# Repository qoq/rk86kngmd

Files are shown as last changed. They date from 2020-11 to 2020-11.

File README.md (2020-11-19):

# rk86kngmd

A replica of 1993 floppy disc controller for "Radio-86RK" computers. Built around i8255 PPI chip (Soviet clone: КР580ВВ55А) and a handful of discrete logic chips.

This version is a compact rework of the replica. 

- Compact layout
- 74LS series SOIC chips are used instead of DIP 555 logic
- Kept КР580ВВ55А and К155ИР13 as they are much easier to source than i8255 and 74LS198
- 28-pin ROM socket accepts 27C32 or 27C64 EPROM chips
- Added 34-pin standard floppy cable connector and 4-pin Berg power supply connector (+5v/+12v)
- Added AND circutry (2 diodes) to form ROM CS signal from CS1/CS2
- Added two bypass capacitors for stability

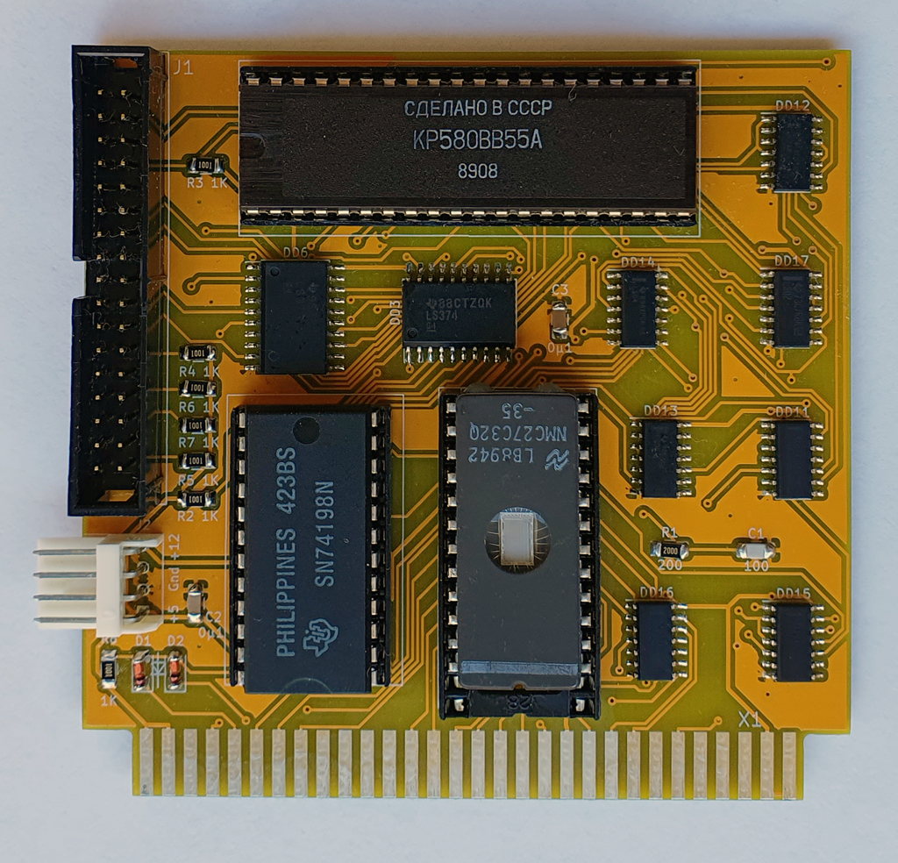
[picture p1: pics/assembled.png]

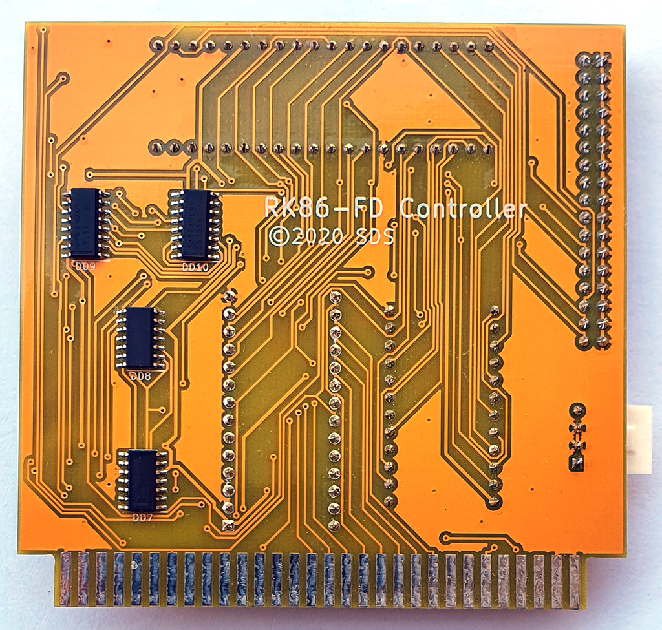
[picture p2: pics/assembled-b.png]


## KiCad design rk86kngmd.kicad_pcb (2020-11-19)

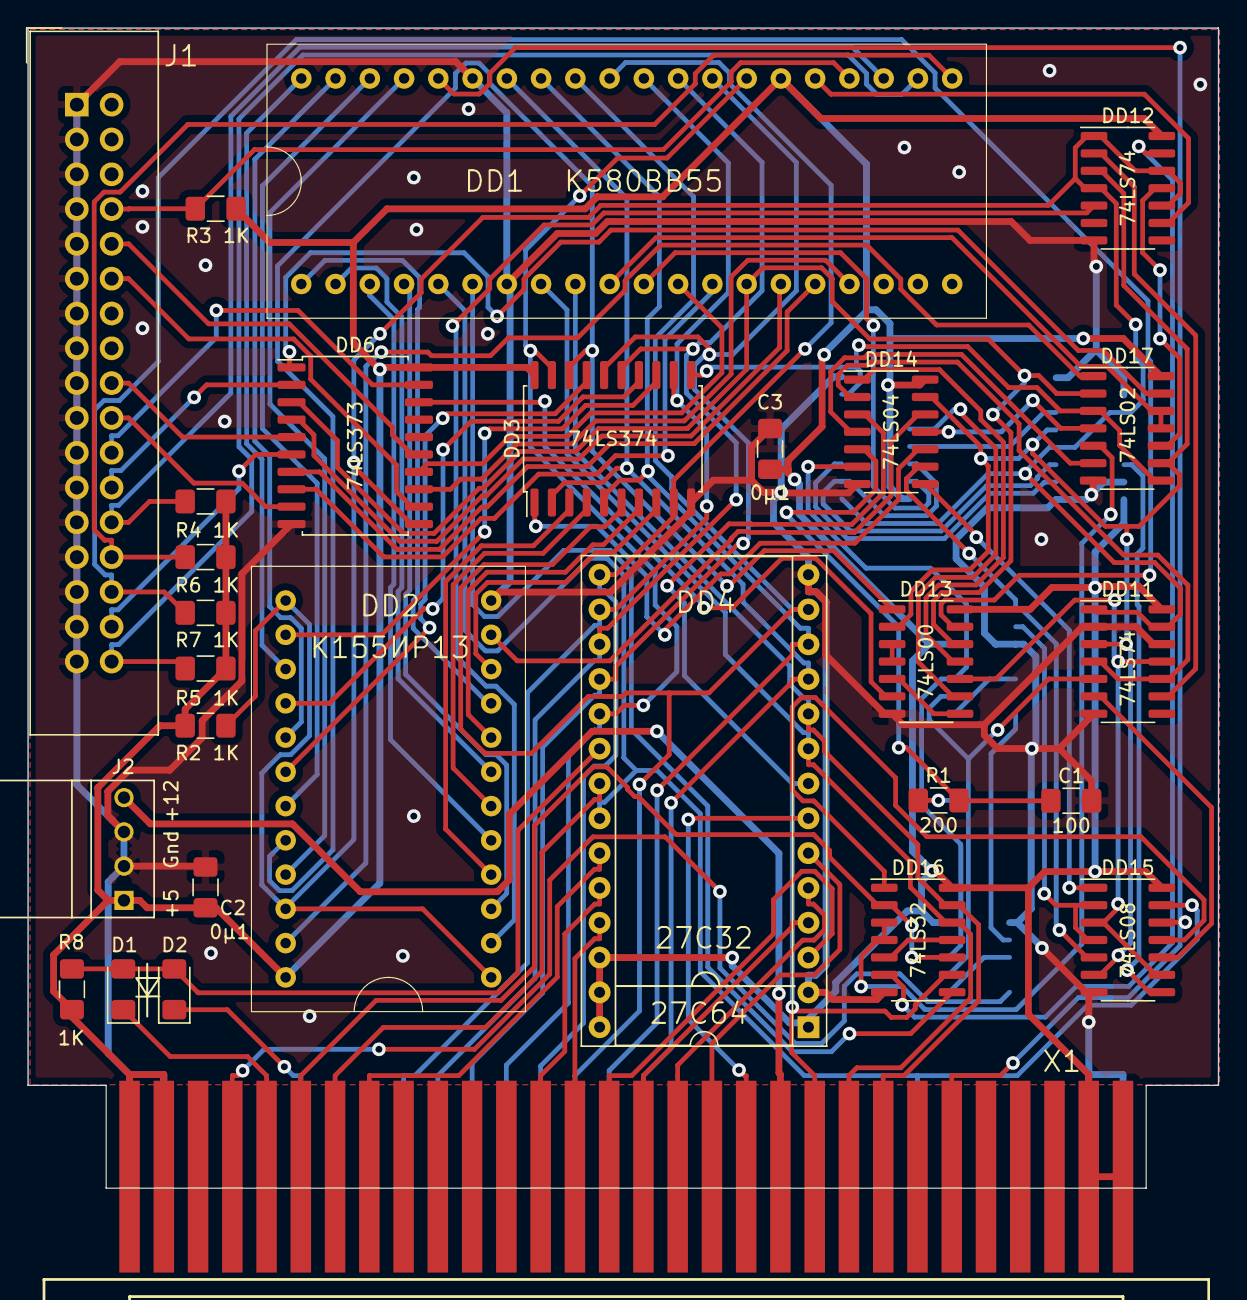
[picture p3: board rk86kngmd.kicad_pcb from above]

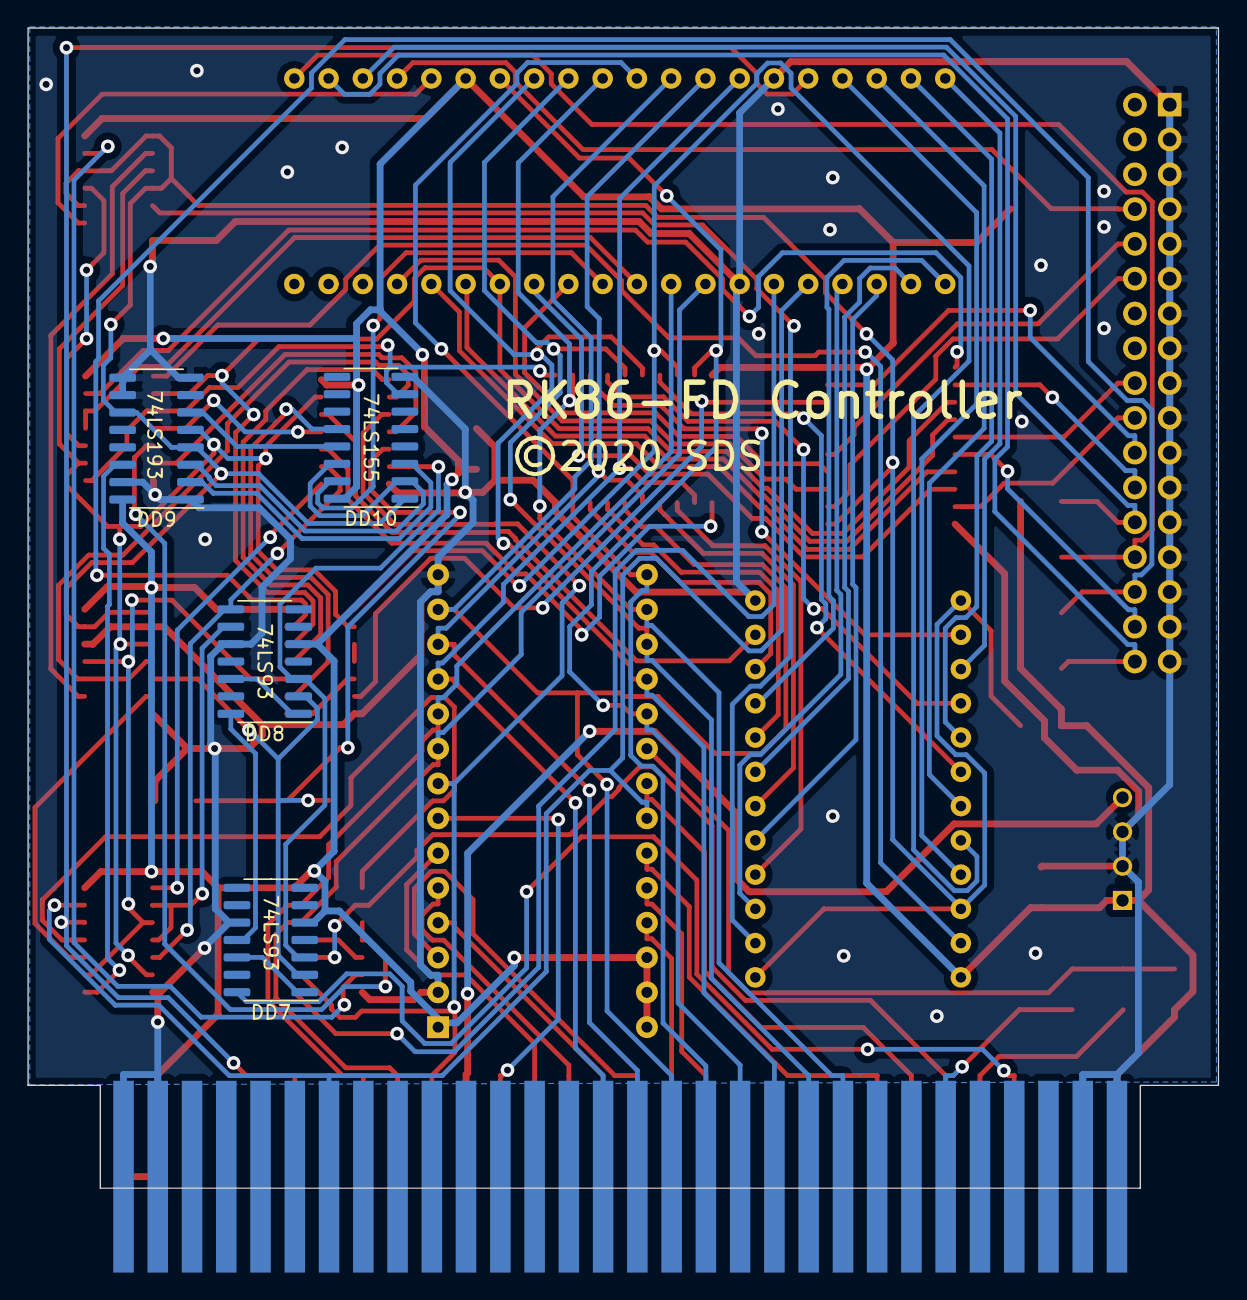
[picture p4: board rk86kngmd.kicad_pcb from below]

Board: 2 copper layers, 86.9 x 84.7 mm, 32 parts (4 on the bottom side), 105 nets.

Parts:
C1: 100; C_1206_3216Metric_Pad1.42x1.75mm_HandSolder
C2, C3: 0μ1; C_1206_3216Metric_Pad1.42x1.75mm_HandSolder
D1, D2: 2N4148; D_1206_3216Metric_Pad1.42x1.75mm_HandSolder
DD1: К580ВВ55; DIP40-2.5mm
DD2: К155ИР13; DIP24-2.5mm
DD3: 74LS374; SOIC-20W_7.5x12.8mm_P1.27mm
DD4: 27C64; DIP-28_W15.24mm_Socket
DD6: 74LS373; SOIC-20W_7.5x12.8mm_P1.27mm
DD7, DD8: 74LS93; SOIC-14_3.9x8.7mm_P1.27mm
DD9: 74LS193; SOIC-16_3.9x9.9mm_P1.27mm
DD10: 74LS155; SOIC-16_3.9x9.9mm_P1.27mm
DD11, DD12: 74LS74; SOIC-14_3.9x8.7mm_P1.27mm
DD13: 74LS00; SOIC-14_3.9x8.7mm_P1.27mm
DD14: 74LS04; SOIC-14_3.9x8.7mm_P1.27mm
DD15: 74LS08; SOIC-14_3.9x8.7mm_P1.27mm
DD16: 74LS32; SOIC-14_3.9x8.7mm_P1.27mm
DD17: 74LS02; SOIC-14_3.9x8.7mm_P1.27mm
J1: Conn_02x17_Odd_Even; IDC-Header_2x17_P2.54mm_Vertical
J2: FD power; TE_171826-4
R1: 200; R_1206_3216Metric_Pad1.42x1.75mm_HandSolder
R2, R3, R4, R5, R6, R7, R8: 1K; R_1206_3216Metric_Pad1.42x1.75mm_HandSolder
X1: ОНп-КС-23

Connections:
+5V: C2.1, C3.1, DD1.26, DD2.24, DD3.20, DD4.1, DD4.26, DD4.27, DD4.28, DD6.20, DD7.5, DD8.5, DD9.16, DD10.16, DD11.14, DD12.14, DD13.14, DD14.14, DD15.14, DD16.14, DD17.14, J2.1, R2.2, R3.1, R4.1, R5.1, R6.1, R7.1, R8.2, X1.B1, X1.B2, X1.B29, X1.B30
+12V: J2.4, X1.B11
/17: DD2.11, DD14.12
/18: DD3.1, DD14.10
/A0: DD1.9, DD4.10, DD16.13, X1.B8
/A1: DD1.8, DD4.9, DD16.12, X1.B9
/A2: DD4.8, DD14.3, DD16.9, X1.B10
/A3: DD4.7, X1.B12
/A4: DD4.6, X1.B13
/A5: DD4.5, X1.B14
/A6: DD4.4, X1.B15
/A7: DD4.3, X1.B16
/A8: DD4.25, X1.B17
/A9: DD4.24, X1.B18
/A10: DD4.21, X1.B24
/A11: DD4.23, X1.B23
/CS1: D1.1, X1.B26
/CS2: D2.1, X1.A25
/CS3: DD16.2, DD16.10, X1.B25
/CS12: D1.2, D2.2, DD4.20, R8.1
/D0: DD1.34, DD3.2, DD4.11, X1.A15
/D1: DD1.33, DD3.5, DD4.12, X1.A16
/D2: DD1.32, DD3.6, DD4.13, X1.A17
/D3: DD1.31, DD3.9, DD4.15, X1.A18
/D4: DD1.30, DD3.12, DD4.16, X1.A22
/D5: DD1.29, DD3.15, DD4.17, X1.A21
/D6: DD1.28, DD3.16, DD4.18, X1.A20
/D7: DD1.27, DD3.19, DD4.19, X1.A19
/OSC: DD7.14, X1.B27
/PB7: DD1.25, DD12.9
/PC1: DD1.15, DD6.4
/PC2: DD1.16, DD6.7
/PC3: DD1.17, DD6.13
/PC4: DD1.13, DD6.8
/PC5: DD1.12, DD6.14
/PC6: DD1.11, DD10.15
/PC7: DD1.10, DD17.11, DD17.12
/RD: DD1.5, DD4.22, DD15.13, X1.A7
/WR: DD1.36, DD15.12, X1.B6
/WRDATA: DD6.18, DD13.6
/WRGATE: DD1.14, DD6.3, DD13.12, DD17.2
DIR: DD6.5, J1.18
DISC_A: DD6.15, J1.10
DISC_B: DD6.12, J1.12
GND: C1.2, C2.2, C3.2, DD1.7, DD1.35, DD2.12, DD3.10, DD4.2, DD4.14, DD6.10, DD7.10, DD8.10, DD9.1, DD9.8, DD9.9, DD9.10, DD9.15, DD10.8, DD11.2, DD11.7, DD11.12, DD12.7, DD13.7, DD14.7, DD15.7, DD16.7, DD17.7, J1.1, J1.3, J1.5, J1.7, J1.9, J1.11, J1.13, J1.15, J1.17, J1.19, J1.21, J1.23, J1.25, J1.27, J1.29, J1.31, J1.33, J2.2, J2.3, X1.A1, X1.A2, X1.A29, X1.A30
IP: DD1.24, J1.8, R3.2
unnamed: C1.1, DD14.5, R1.2
unnamed: DD1.1, DD2.9
unnamed: DD1.2, DD2.7
unnamed: DD1.3, DD2.5
unnamed: DD1.4, DD2.3
unnamed: DD1.6, DD16.8
unnamed: DD1.37, DD2.21
unnamed: DD1.38, DD2.19
unnamed: DD1.39, DD2.17
unnamed: DD1.40, DD2.15
unnamed: DD2.4, DD3.3
unnamed: DD2.6, DD3.4
unnamed: DD2.8, DD3.7
unnamed: DD2.10, DD3.8
unnamed: DD2.14, DD3.13
unnamed: DD2.16, DD3.14
unnamed: DD2.18, DD3.17
unnamed: DD7.1, DD7.12
unnamed: DD7.11, DD8.14
unnamed: DD8.1, DD8.12
unnamed: DD2.1, DD2.13, DD2.22, DD6.11, DD9.4, DD9.11, DD10.1, DD11.1, DD11.13, DD12.1, DD12.4, DD12.10, DD12.12, R2.1
unnamed: DD9.2, DD10.3
unnamed: DD3.11, DD10.7, DD17.3, DD17.8
unnamed: DD10.12, DD13.9
unnamed: DD9.6, DD10.13
unnamed: DD9.3, DD10.2, DD10.14
unnamed: DD9.5, DD11.3, DD12.3, DD13.2, DD14.13, DD15.6, DD17.9
unnamed: DD7.2, DD8.2, DD11.5, R1.1
unnamed: DD11.6, DD15.10
unnamed: DD11.9, DD12.2
unnamed: DD11.4, DD11.10, DD14.2
unnamed: DD11.11, DD13.10, DD15.3, DD15.9
unnamed: DD2.2, DD12.5
unnamed: DD12.11, DD17.10
unnamed: DD12.13, DD16.6
unnamed: DD2.20, DD3.18, DD13.1
unnamed: DD13.3, DD13.4
unnamed: DD13.5, DD13.8
unnamed: DD13.11, DD14.1
unnamed: DD14.4, DD17.6
unnamed: DD7.3, DD8.3, DD14.6
unnamed: DD14.8, DD15.1
unnamed: DD8.8, DD14.9, DD15.5
unnamed: DD14.11, DD17.4
unnamed: DD8.9, DD15.2, DD15.4
unnamed: DD9.14, DD15.8
unnamed: DD15.11, DD16.1
unnamed: DD16.3, DD16.4, DD17.5
unnamed: DD16.5, DD16.11
unnamed: DD2.23, DD17.1
unnamed: DD6.1, DD17.13
RD_DATA: DD13.13, J1.30, R7.2
READY: DD1.22, J1.34, R5.2
SIDE: DD6.6, J1.32
STEP: DD6.9, J1.20
TR00: DD1.23, J1.26, R4.2
WPRT: DD1.21, J1.28, R6.2
WR_DATA: DD6.19, J1.22
WR_GATE: DD6.2, J1.24

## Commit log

2020-08-01 Updated libraries
    [rk86kngmd.kicad_pcb, rk86kngmd.sch]
2020-08-02 board routed
    [rk86kngmd-B_Cu.gbr, rk86kngmd-B_Mask.gbr, rk86kngmd-B_SilkS.gbr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]
2020-11-19 Switched to SMD components
    [rk86kngmd-B_Cu.gbr, rk86kngmd-B_Mask.gbr, rk86kngmd-B_SilkS.gbr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]
2020-12-19 minor updates
    [rk86kngmd.sch]

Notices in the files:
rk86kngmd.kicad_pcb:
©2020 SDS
